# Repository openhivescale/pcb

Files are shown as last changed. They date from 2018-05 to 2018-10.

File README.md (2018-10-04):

PCB schemas and boards, eagle format (7.5)

mainboard is... the main board, with MCU including wifi, power, motor driver etc...

On this mainboard can be plugged ONE of the shield : 

- SFM10R1 : sifgox (Europe)
- RN2483A : LoraWan
- SIM800L : GSM 2G
- SIM7000E : GSM 4G Nb-IoT

- template : base for a future new shield

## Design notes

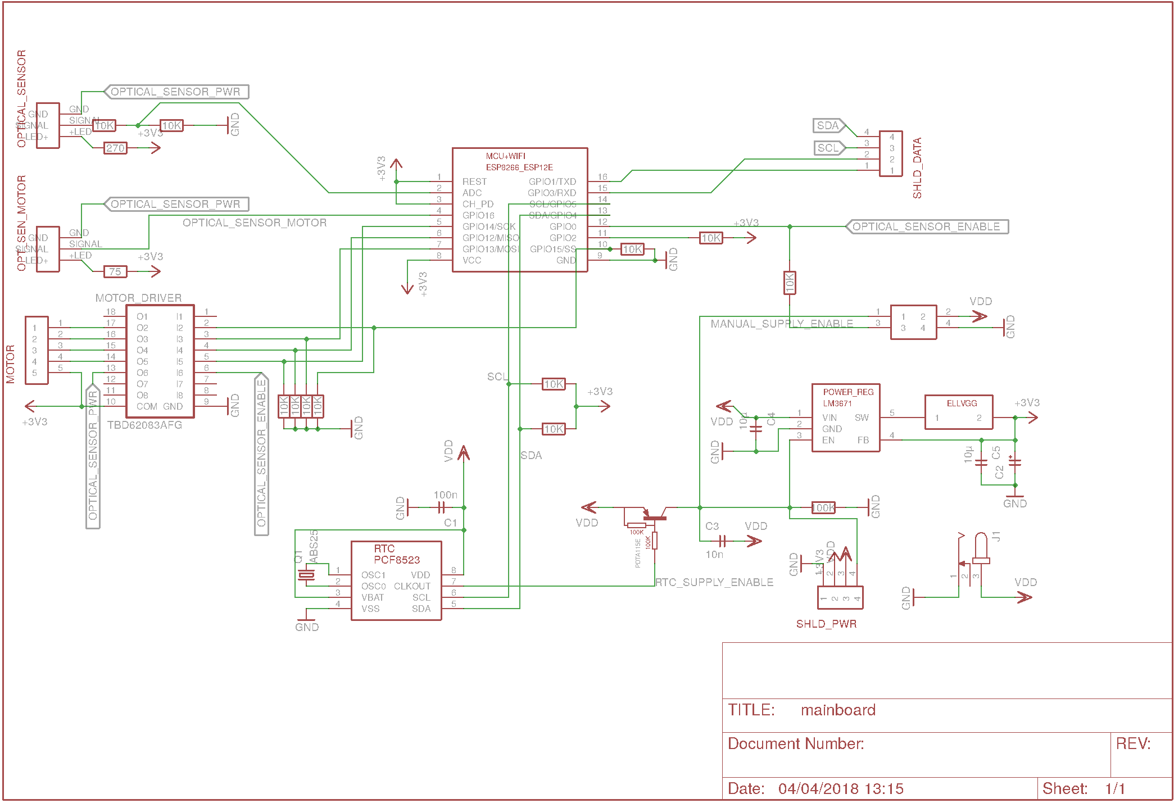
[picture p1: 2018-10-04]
mainboard_sch.png

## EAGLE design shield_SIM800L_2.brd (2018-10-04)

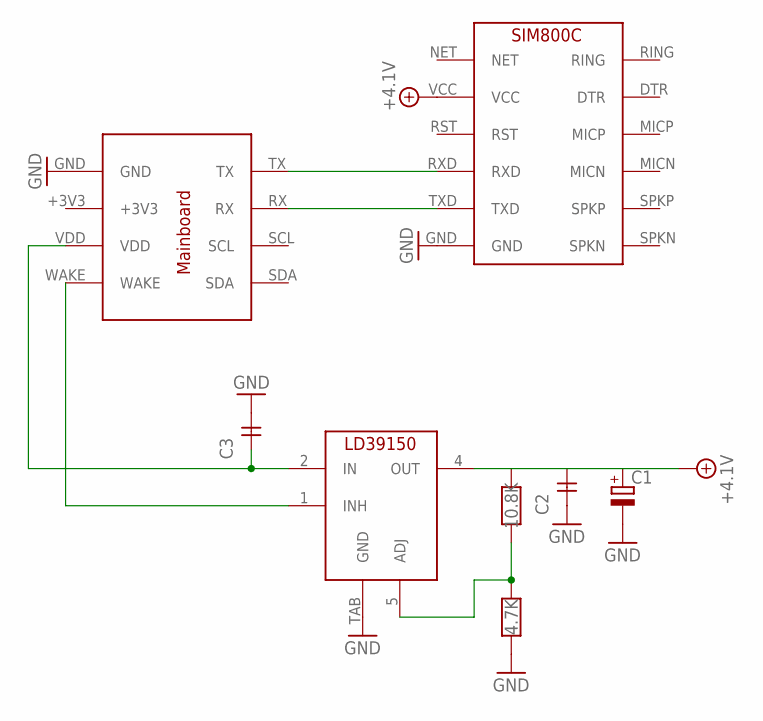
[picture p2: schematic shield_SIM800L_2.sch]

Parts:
C1: CPOL-EUE5-13; E5-13
C2, C3: CSMD_1206; SMD_RC_1206
R1: 10.8K; SMD_RC_1206
R2: 4.7K; SMD_RC_1206
U$1: SHIELD
U$2: LD39150PT-R; PPAK
U$6: SIM800L

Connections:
+3V3: U$1.+3V3
+4.1V: C1.+, C2.P$2 (2), R1.P$1, U$2.4 (OUT), U$6.VCC
GND: C1.-, C2.P$1 (1), C3.P$2 (2), R2.P$2, U$1.GND, U$2.TAB (GND), U$6.GND
unnamed: U$1.RX, U$6.TXD
unnamed: U$1.TX, U$6.RXD
unnamed: R1.P$2, R2.P$1, U$2.5 (ADJ)
unnamed: C3.P$1 (1), U$1.VDD, U$2.2 (IN)
unnamed: U$1.WAKE, U$2.1 (INH)

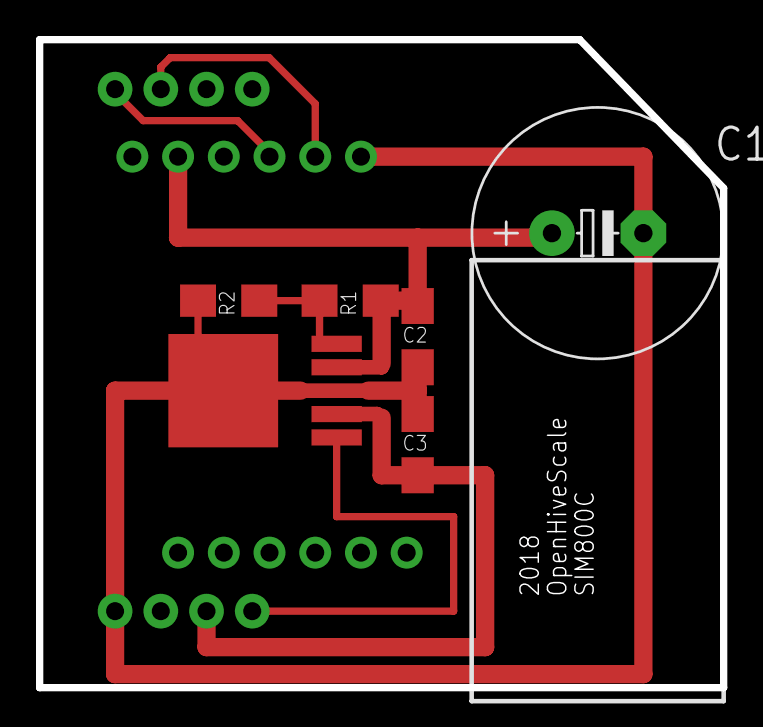
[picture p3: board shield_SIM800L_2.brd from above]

Board: 2 copper layers, 38.0 x 36.0 mm, 8 parts (1 on the bottom side), 7 nets.

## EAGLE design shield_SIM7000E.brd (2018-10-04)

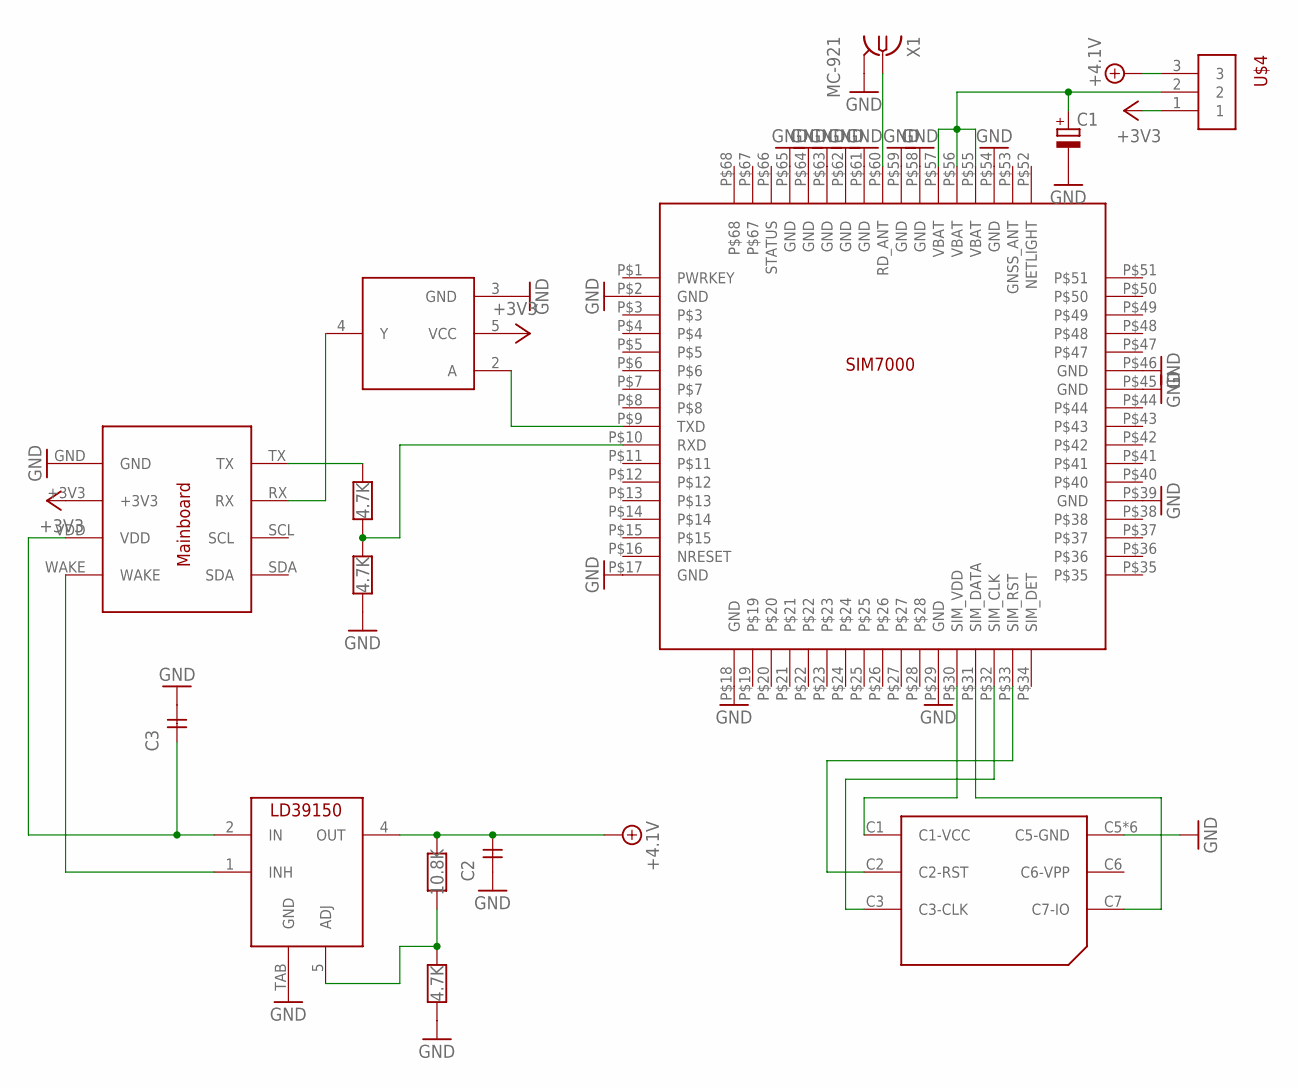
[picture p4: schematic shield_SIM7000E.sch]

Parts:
C1: CPOL-EUE5-13; E5-13
C2, C3: CSMD_1206; SMD_RC_1206
R1: 10.8K; SMD_RC_1206
R2, R3, R4: 4.7K; SMD_RC_1206
U$1: SHIELD
U$2: LD39150PT-R; PPAK
U$3: SIM7000
U$4: HEADER_1X3
U$5: SN75LV1T34; SOT23-5L-SIMPLE
U$6: SIM_SCYT
X1: MC-921

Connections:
+3V3: U$1.+3V3, U$4.1, U$5.5 (VCC)
+4.1V: C2.P$2 (2), R1.P$1, U$2.4 (OUT), U$4.3
GND: C1.-, C2.P$1 (1), C3.P$2 (2), R2.P$2, R4.P$1, U$1.GND, U$2.TAB (GND), U$3.P$2 (GND), U$3.P$17 (GND), U$3.P$18 (GND), U$3.P$29 (GND), U$3.P$39 (GND), U$3.P$45 (GND), U$3.P$46 (GND), U$3.P$54 (GND), U$3.P$58 (GND), U$3.P$59 (GND), U$3.P$61 (GND), U$3.P$62 (GND), U$3.P$63 (GND), U$3.P$64 (GND), U$3.P$65 (GND), U$5.3 (GND), U$6.C5 (C5-GND), U$6.GND@1 (C5-GND), U$6.GND@2 (C5-GND), U$6.GND@3 (C5-GND), U$6.GND@4 (C5-GND), U$6.GND@5 (C5-GND), X1.2@1 (GND), X1.2@2 (GND)
unnamed: R3.P$2, U$1.TX
unnamed: C1.+, U$3.P$55 (VBAT), U$3.P$56 (VBAT), U$3.P$57 (VBAT), U$4.2
unnamed: R1.P$2, R2.P$1, U$2.5 (ADJ)
unnamed: C3.P$1 (1), U$1.VDD, U$2.2 (IN)
unnamed: U$1.WAKE, U$2.1 (INH)
unnamed: U$3.P$9 (TXD), U$5.2 (A)
unnamed: R3.P$1, R4.P$2, U$3.P$10 (RXD)
unnamed: U$1.RX, U$5.4 (Y)
unnamed: U$3.P$30 (SIM_VDD), U$6.C1 (C1-VCC)
unnamed: U$3.P$31 (SIM_DATA), U$6.C7 (C7-IO)
unnamed: U$3.P$32 (SIM_CLK), U$6.C3 (C3-CLK)
unnamed: U$3.P$33 (SIM_RST), U$6.C2 (C2-RST)
unnamed: U$3.P$60 (RD_ANT), X1.1

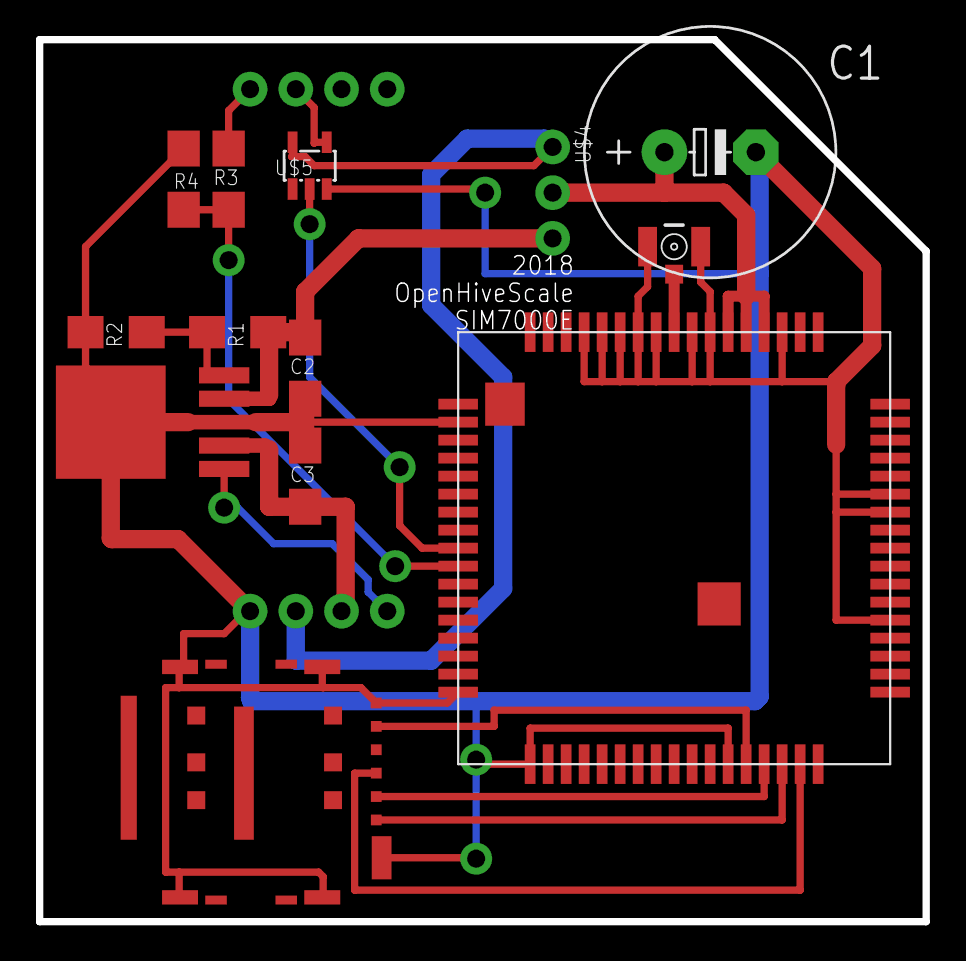
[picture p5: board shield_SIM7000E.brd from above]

Board: 2 copper layers, 49.2 x 49.0 mm, 14 parts (0 on the bottom side), 16 nets.

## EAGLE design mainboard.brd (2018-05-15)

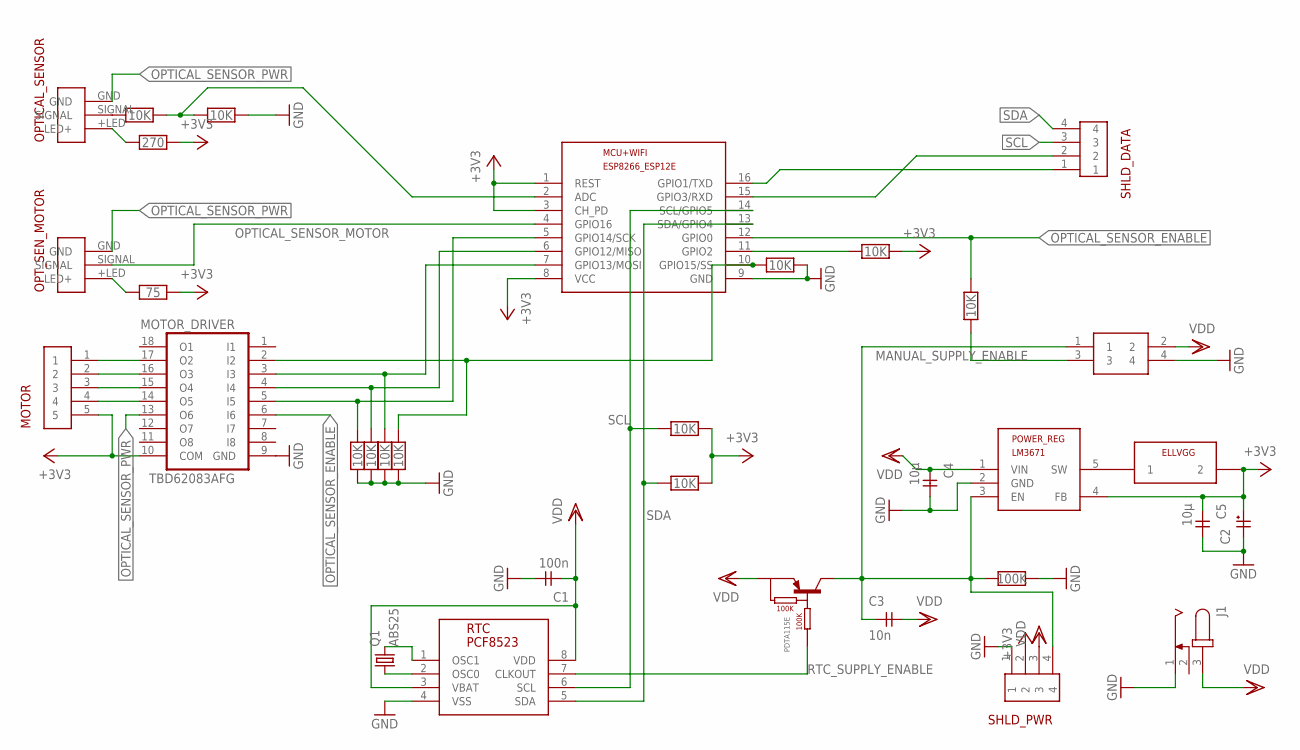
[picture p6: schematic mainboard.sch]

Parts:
C1: 100n; SMD_RC_1206
C2: C_POLSMD_M6.3; C_M6.3
C3: 10n; SMD_RC_1206
C4, C5: 10µ; SMD_RC_1206
DIL_SWITCH: HEADER_2X2
J1: JACK-PLUG0; SPC4077
L1: ELLVGG
MCU+WIFI: ESP8266-12EESP8266-ESP12E; ESP8266-ESP12E
MOTOR: B5B-XH-A
MOTOR_DRIVER: TBD62083AFG; SO18
OPTICAL_SENSOR: ENDSTOP
OPT_SEN_MOTOR: ENDSTOP
POWER_REG: LM3671NO_EXTRA_PAD; SOT23-5L-SIMPLE
Q1: ABS25
R1: 270; SMD_RC_1206
R2, R3, R5, R6, R7, R8, R9, R10, R11, R12, R13: 10K; SMD_RC_1206
R4: 100K; SMD_RC_1206
R14: 75; SMD_RC_1206
RTC: PCF8523TS; SO8
SHLD_DATA: HEADER_1X4
SHLD_PWR: HEADER_1X4
T1: PDTA115ET; SOT23

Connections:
+3V3: C2.+, C5.P$1 (1), L1.P$2 (2), MCU+WIFI.1 (REST), MCU+WIFI.3 (CH_PD), MCU+WIFI.8 (VCC), MOTOR.5, MOTOR_DRIVER.10 (COM), POWER_REG.4 (FB), R1.P$2, R9.P$2, R10.P$2, R11.P$2, R14.P$2, SHLD_PWR.2
GND: C1.P$2 (2), C2.GND, C4.P$2 (2), C5.P$2 (2), DIL_SWITCH.4, J1.1, MCU+WIFI.9 (GND), MOTOR_DRIVER.9 (GND), POWER_REG.2 (GND), R3.P$2, R4.P$1, R5.P$1, R6.P$1, R7.P$2, R12.P$1, R13.P$1, RTC.4 (VSS), SHLD_PWR.1
MANUAL_SUPPLY_ENABLE: C3.P$1 (1), DIL_SWITCH.1, POWER_REG.3 (EN), R4.P$2, SHLD_PWR.4, T1.3 (C)
unnamed: MOTOR.1, MOTOR_DRIVER.17 (O2)
unnamed: Q1.4 (2), RTC.1 (OSC1)
unnamed: L1.P$1 (1), POWER_REG.5 (SW)
unnamed: MOTOR.2, MOTOR_DRIVER.16 (O3)
unnamed: MCU+WIFI.7 (GPIO13/MOSI), MOTOR_DRIVER.3 (I3), R12.P$2
unnamed: MCU+WIFI.6 (GPIO12/MISO), MOTOR_DRIVER.4 (I4), R6.P$2
unnamed: MOTOR.3, MOTOR_DRIVER.15 (O4)
unnamed: MOTOR.4, MOTOR_DRIVER.14 (O5)
unnamed: OPT_SEN_MOTOR.+LED (LED+), R14.P$1
unnamed: MCU+WIFI.11 (GPIO2), R11.P$1
unnamed: MCU+WIFI.16 (GPIO1/TXD), SHLD_DATA.1
unnamed: MCU+WIFI.15 (GPIO3/RXD), SHLD_DATA.2
unnamed: MCU+WIFI.5 (GPIO14/SCK), MOTOR_DRIVER.5 (I5), R5.P$2
unnamed: MCU+WIFI.10 (GPIO15/SS), MOTOR_DRIVER.2 (I2), R7.P$1, R13.P$2
unnamed: MCU+WIFI.2 (ADC), R2.P$2, R3.P$1
unnamed: DIL_SWITCH.3, R8.P$2
unnamed: OPTICAL_SENSOR.SIGNAL, R2.P$1
unnamed: OPTICAL_SENSOR.+LED (LED+), R1.P$1
OPTICAL_SENSOR_ENABLE: MCU+WIFI.12 (GPIO0), MOTOR_DRIVER.6 (I6), R8.P$1
OPTICAL_SENSOR_MOTOR: MCU+WIFI.4 (GPIO16), OPT_SEN_MOTOR.SIGNAL
OPTICAL_SENSOR_PWR: MOTOR_DRIVER.13 (O6), OPTICAL_SENSOR.GND, OPT_SEN_MOTOR.GND
RTC_OSC: Q1.1, RTC.2 (OSC0)
RTC_SUPPLY_ENABLE: RTC.7 (CLKOUT), T1.1 (B)
SCL: MCU+WIFI.14 (SCL/GPIO5), R9.P$1, RTC.6 (SCL), SHLD_DATA.3
SDA: MCU+WIFI.13 (SDA/GPIO4), R10.P$1, RTC.5 (SDA), SHLD_DATA.4
VDD: C1.P$1 (1), C3.P$2 (2), C4.P$1 (1), DIL_SWITCH.2, J1.3, POWER_REG.1 (VIN), RTC.3 (VBAT), RTC.8 (VDD), SHLD_PWR.3, T1.2 (E)

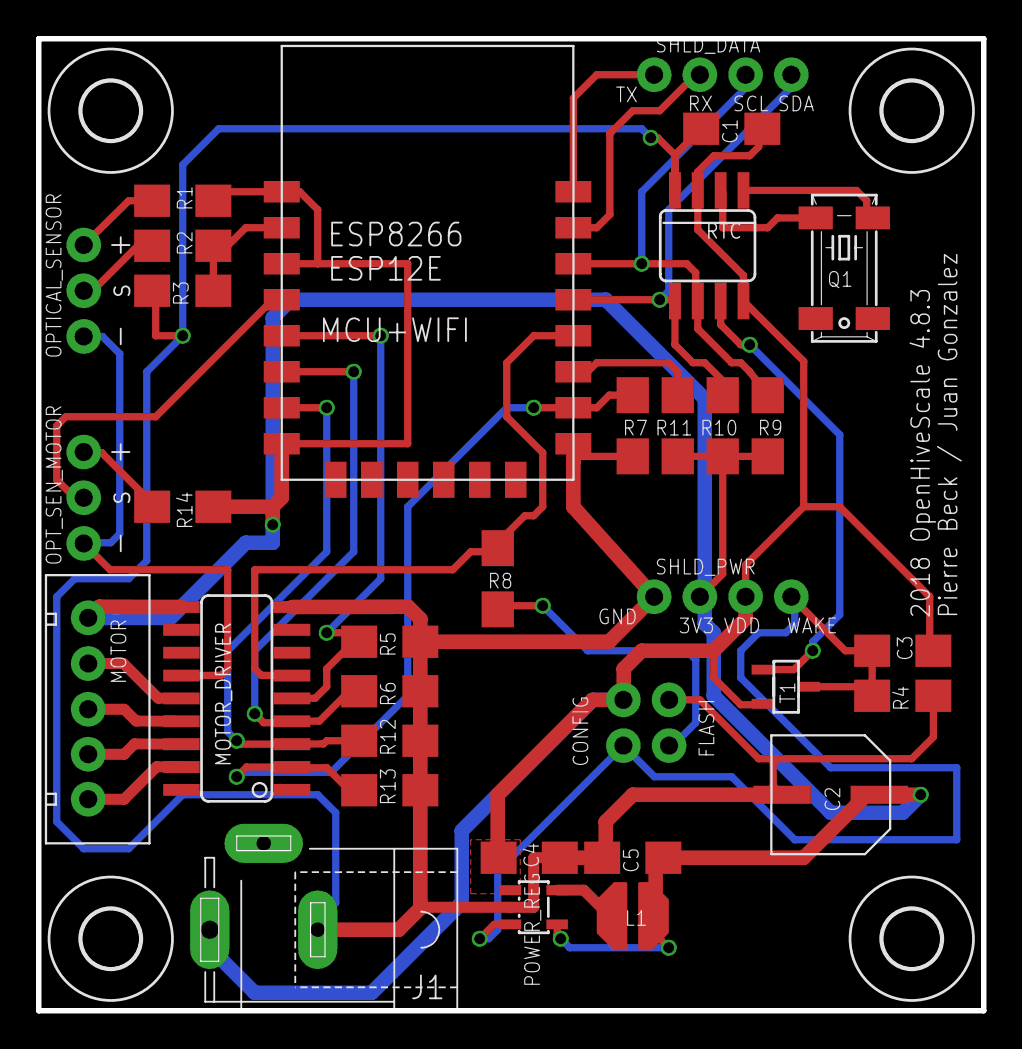
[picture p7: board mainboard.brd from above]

Board: 2 copper layers, 52.5 x 54.0 mm, 37 parts (0 on the bottom side), 29 nets.

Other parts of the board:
U$2, U$3, U$4, U$5: 3,2

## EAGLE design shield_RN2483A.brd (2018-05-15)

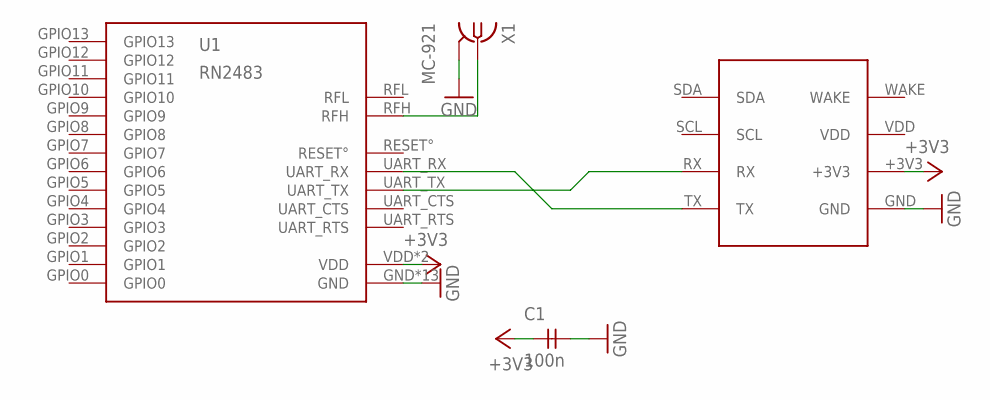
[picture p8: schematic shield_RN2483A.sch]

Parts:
C1: 100n; SMD_RC_1206
U1: RN2483
U$1: SHIELD
X1: MC-921

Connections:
+3V3: C1.P$1 (1), U1.VDD, U1.VDD2 (VDD), U$1.+3V3
GND: C1.P$2 (2), U1.GND, U1.GND1 (GND), U1.GND2 (GND), U1.GND3 (GND), U1.GND4 (GND), U1.GND5 (GND), U1.GND6 (GND), U1.GND7 (GND), U1.GND8 (GND), U1.GND9 (GND), U1.GND10 (GND), U1.GND11 (GND), U1.GND12 (GND), U$1.GND, X1.2@1 (GND), X1.2@2 (GND)
unnamed: U1.UART_TX, U$1.RX
unnamed: U1.UART_RX, U$1.TX
unnamed: U1.RFH, X1.1
VDD: U$1.VDD

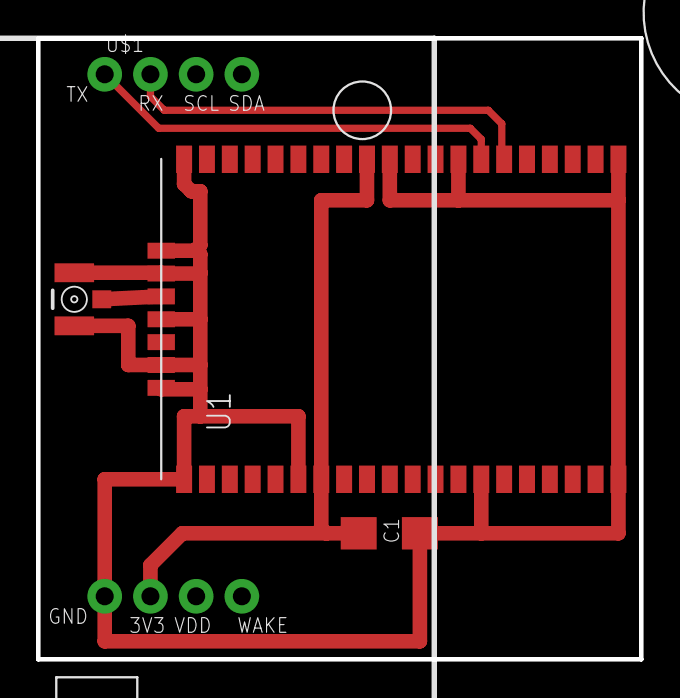
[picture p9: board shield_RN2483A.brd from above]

Board: 2 copper layers, 33.5 x 34.5 mm, 4 parts (0 on the bottom side), 5 nets.

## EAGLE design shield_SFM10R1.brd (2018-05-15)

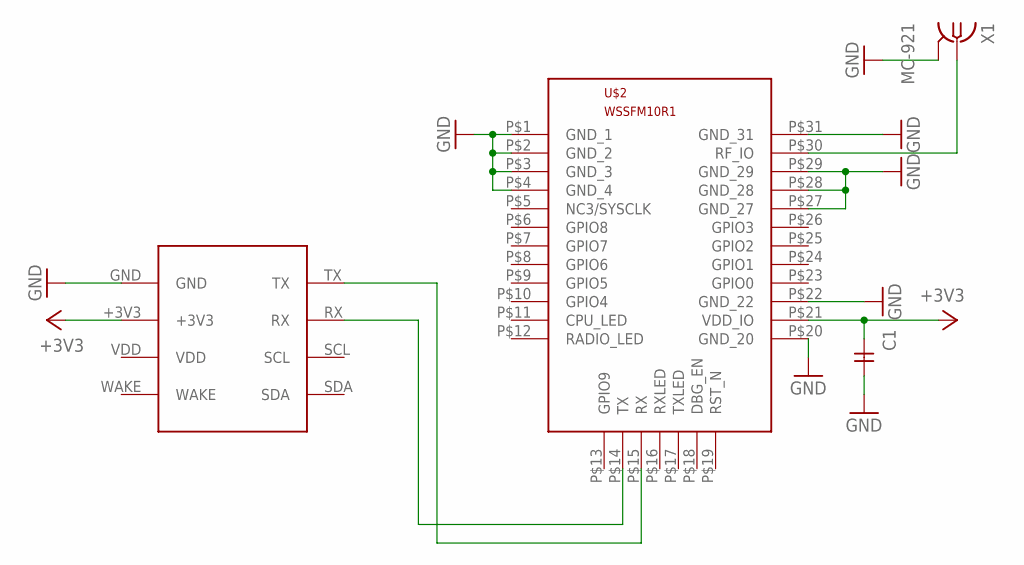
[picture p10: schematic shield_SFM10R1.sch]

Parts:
C1: CSMD_1206; SMD_RC_1206
U$1: SHIELD
U$2: SFM10R1
X1: MC-921

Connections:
+3V3: C1.P$1 (1), U$1.+3V3, U$2.P$21 (VDD_IO)
GND: C1.P$2 (2), U$1.GND, U$2.P$1 (GND_1), U$2.P$2 (GND_2), U$2.P$3 (GND_3), U$2.P$4 (GND_4), U$2.P$20 (GND_20), U$2.P$22 (GND_22), U$2.P$27 (GND_27), U$2.P$28 (GND_28), U$2.P$29 (GND_29), U$2.P$31 (GND_31), X1.2@1 (GND), X1.2@2 (GND)
unnamed: U$1.TX, U$2.P$15 (RX)
unnamed: U$1.RX, U$2.P$14 (TX)
unnamed: U$2.P$30 (RF_IO), X1.1
VDD: U$1.VDD

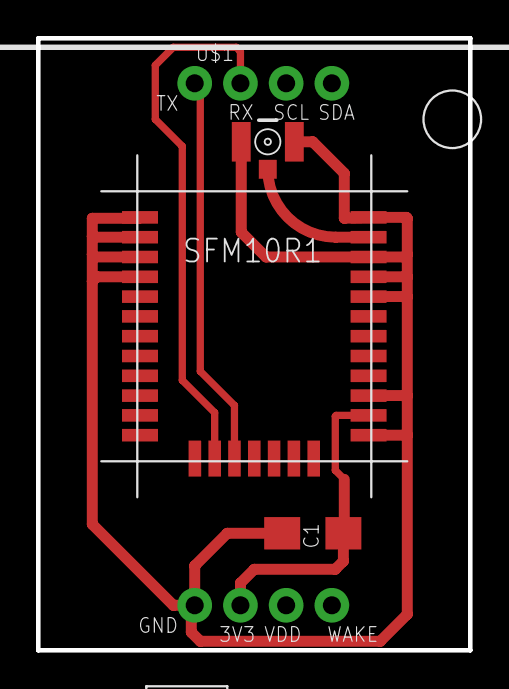
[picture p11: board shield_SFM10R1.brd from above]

Board: 2 copper layers, 24.0 x 34.0 mm, 4 parts (0 on the bottom side), 5 nets.

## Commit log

2018-10-04 schema en png
    [shield_SIP800L.brd, shield_SIP800L.sch]
2018-10-04 SIM800 v2 + SIM7000
    [shield_SIM7000E.brd, shield_SIM7000E.sch, shield_SIM800L_2.brd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]
2018-10-04 removed v1 of SIM800L, that doesn't work reliably
    [shield_SIM800L.brd, shield_SIM800L.sch]
